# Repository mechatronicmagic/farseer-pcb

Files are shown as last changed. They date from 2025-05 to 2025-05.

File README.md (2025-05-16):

- [Repository Info](#org3efd3b6)
- [Images](#org4000d6c)
- [Schematic](#org9702aa9)
- [PCB](#orgc4c3abc)
- [Bill of Materials](#org9a89b54)
- [Development](#org04cc7a2)

    <!-- This file is generated automatically from metadata -->
    <!-- File edits may be overwritten! -->

# Repository Info

-   Project Name: farseer\_pcb
-   Synopsis: Measures fly wingbeats using IR light reflected from flapping fly wings.
-   Documentation Version: 1.0.0
-   Pcb Version: 1.0
-   Enclosure Version: 1.0
-   Supplemental BOM Version: 1.0
-   Release Date: 2025-05-16
-   Creation Date: 2025-05-16
-   Kicad Version: 9.0.0
-   License: GPL-3.0
-   URL: <https://github.com/mechatronicmagic/farseer_pcb>
-   Author: Peter Polidoro
-   Email: peter@polidoro.io
-   Copyright: 2025 Peter Polidoro
-   References:
    -   [kicad](https://www.kicad.org/)
    -   [light\_sensor\_boards](https://github.com/janelia-kicad/light_sensor_boards)
    -   [wingbeat\_detector](https://github.com/peterpolidoro/wingbeat_detector)
-   Papers:
    -   [Active antennal movements in Drosophila can tune wind encoding](https://doi.org/10.1016/j.cub.2023.01.020)
    -   [A novel assay to evaluate action selection in escape behavior](https://doi.org/10.1016/j.jneumeth.2018.04.019)
    -   [Cellular evidence for efference copy in Drosophila visuomotor processing](https://doi.org/10.1038/nn.4083)
    -   [State-dependent decoupling of sensory and motor circuits underlies behavioral flexibility in Drosophila](https://doi.org/10.1038/s41593-019-0413-4)
    -   [Active flight increases the gain of visual motion processing in Drosophila](https://doi.org/10.1038/nn.2492)
    -   [An Optical Tachometer for Measurement of the Wing-Beat Frequency of Free-Flying Insects](https://doi.org/10.1242/jeb.82.1.377)

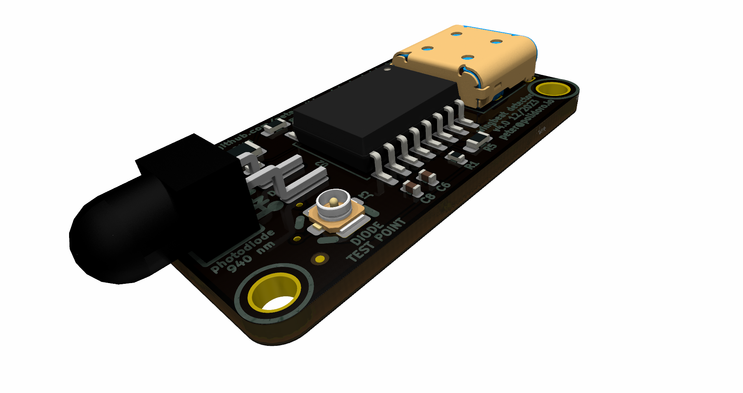
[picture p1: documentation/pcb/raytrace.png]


This wingbeat detector, or flight “tachometer”, is a small electro-optical device that uses reflected infrared light from the fly’s wingbeats to generate an oscillating voltage signal. The oscillation frequency of the voltage signal matches, and thus allows one to measure, the tethered fly's wingbeat frequency.

This device is useful for plate (rather than pin) tethered flight experiments, because with plate-glued flies, one cannot extract the wingbeat frequency via a classical wingbeat analyzer. Microphones have also been used for extracting wingbeat frequency, but they require a quiet room. This wingbeat detector is immune to audible noise and only requires an infrared light source, often already present on flight rigs for video recording.

One end of a small diameter light guide is mounted near the fly and aimed at the wings. The other end of the light guide is in a small enclosure containing an optical filter and printed circuit board and can be mounted off to the side of the rig wherever there is room.

The light guide brings light reflected off of the wings down to a photodiode on a circuit board, after passing through an optical filter to remove the unwanted wavelengths of light. Amplifiers and filters on the circuit board convert the tiny amounts of current from the photodiode into an oscillating voltage signal, with a frequency range of several hundred Hertz and a magnitude range of several Volts.

The oscillating voltage signal can be fed into a data acquisition card, oscilloscope, and/or a speaker for recording and instant feedback on fly wingbeat frequency. Using a threshold, the signal can be used as a simple boolean that indicates whether the tethered animal is flying or not for triggering experiments or synchronizing the data collection.

This device was first created at Caltech in the Dickinson lab in collaboration with Gaby Maimon around 2010. It has transformed over several generations, getting smaller and more robust each iteration. It has been used on rigs in multiple universities and research institutes and has been referenced in several papers. A couple of iterations were designed in collaboration with Sung Soo Kim and the Card lab at Janelia Research Campus. The latest version was created in collaboration with the Suver lab at Vanderbilt.

# Images

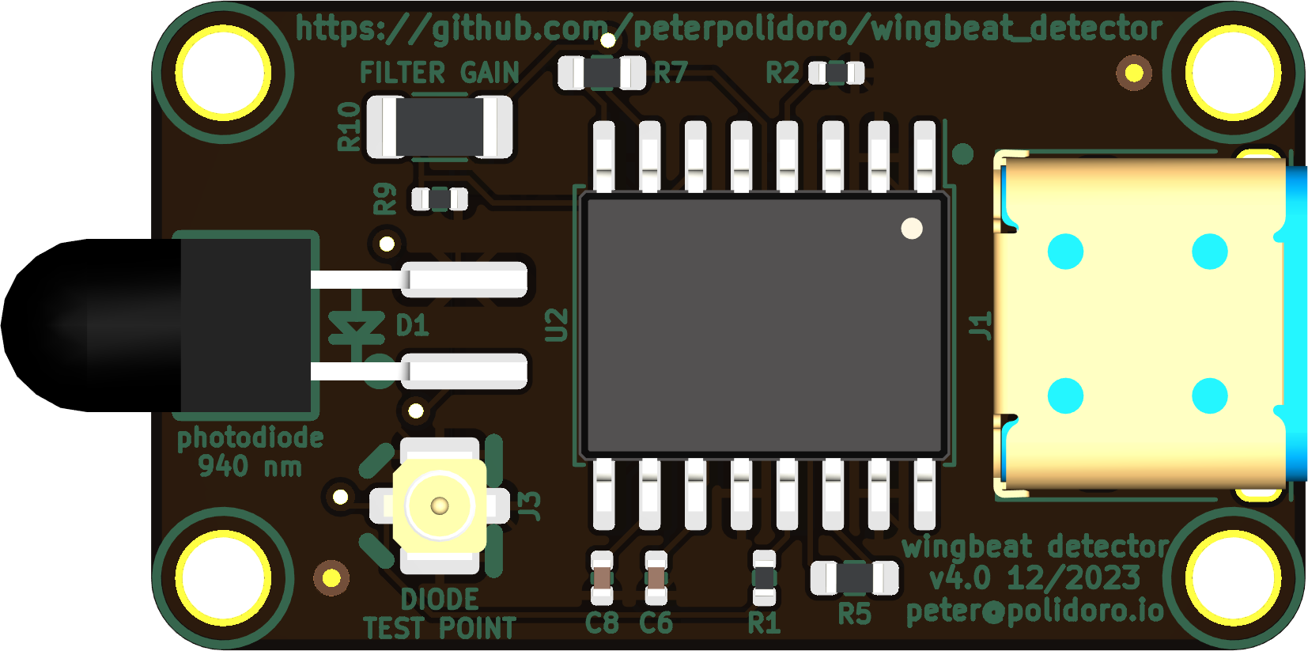
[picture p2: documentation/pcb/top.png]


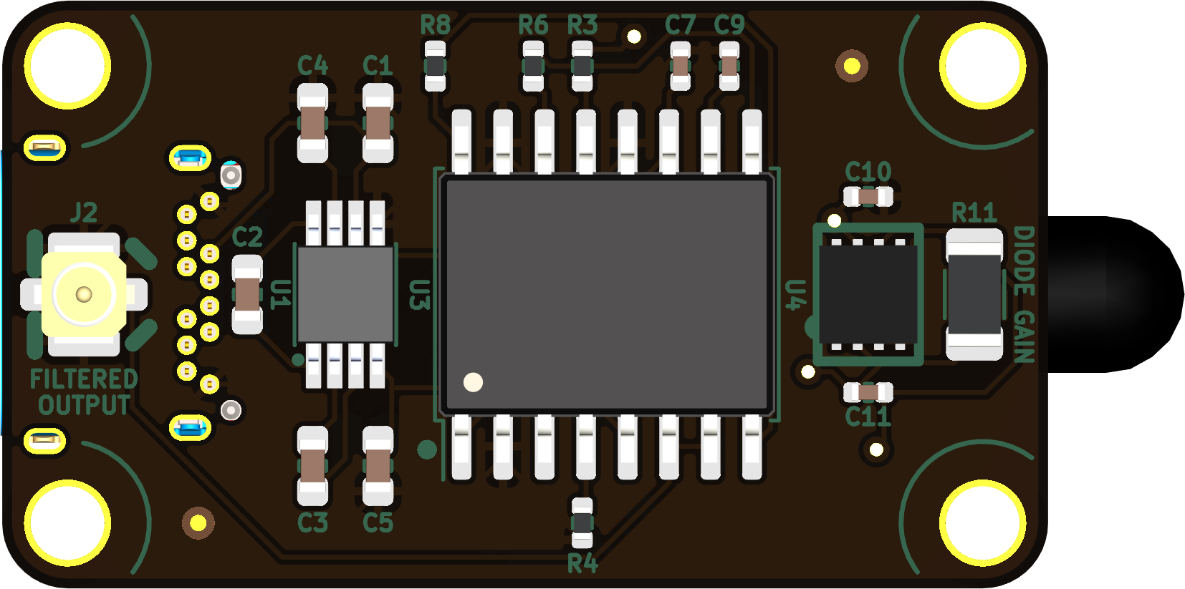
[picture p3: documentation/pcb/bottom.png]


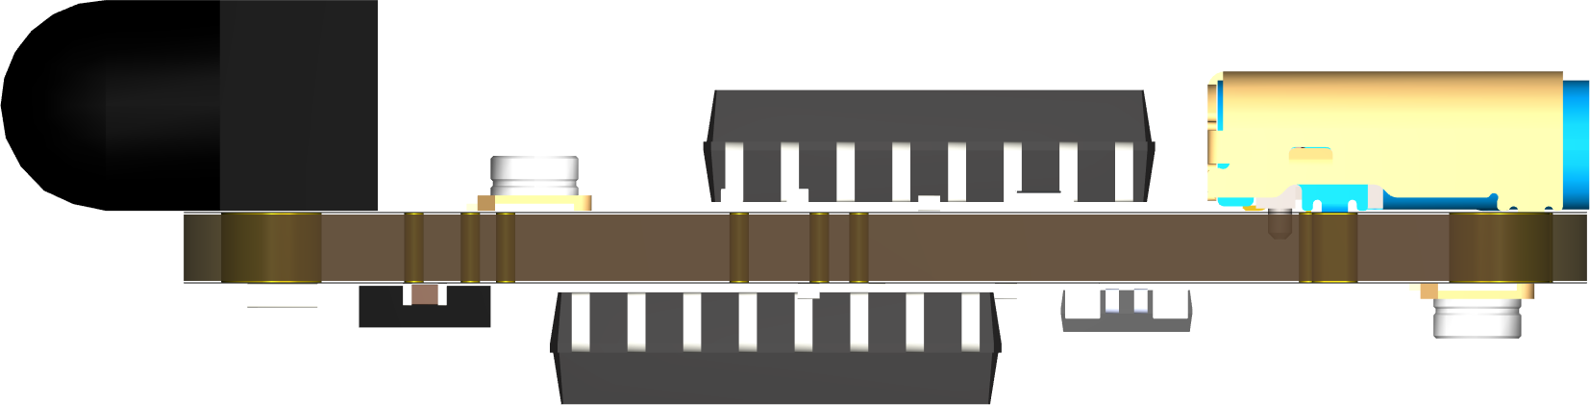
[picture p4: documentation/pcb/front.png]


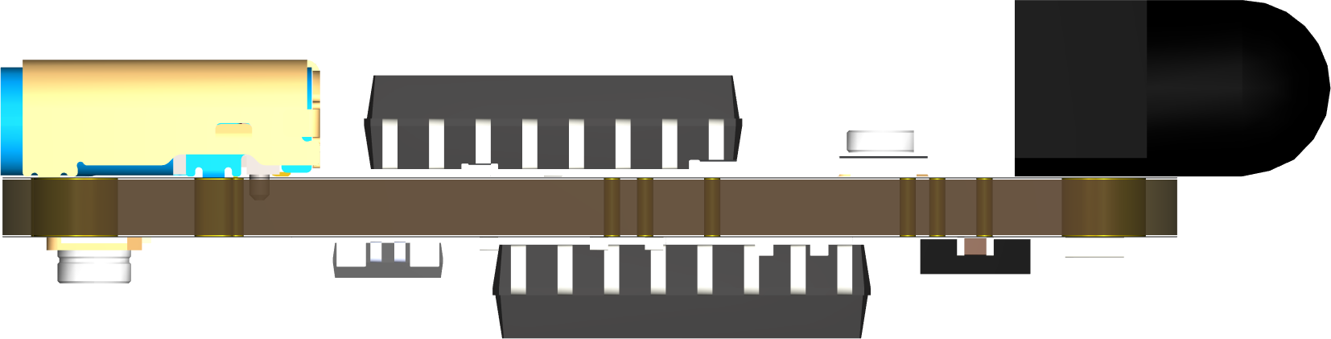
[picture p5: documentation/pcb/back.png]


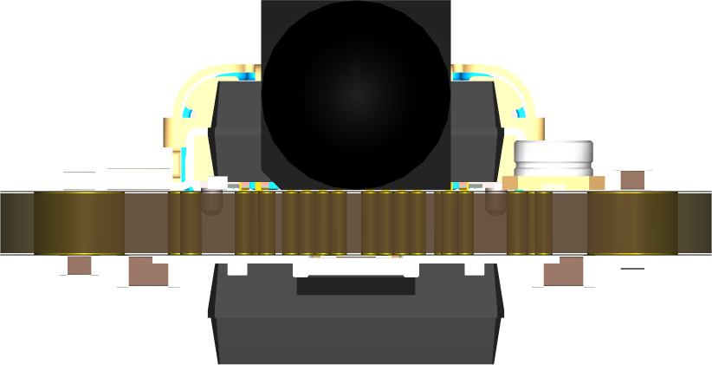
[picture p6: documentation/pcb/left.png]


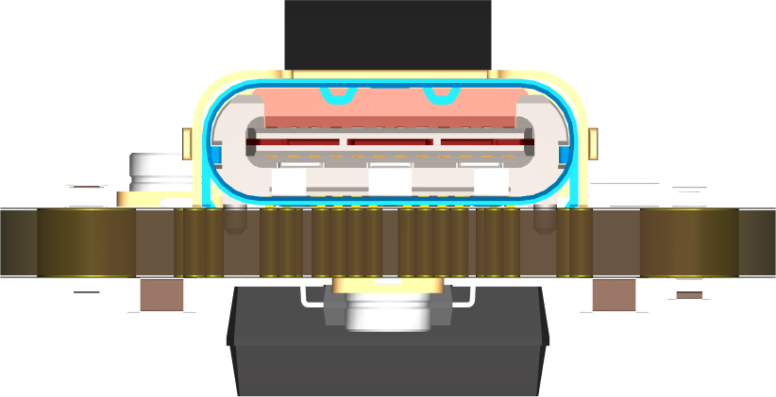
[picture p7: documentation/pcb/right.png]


# Schematic

[./documentation/schematic/wingbeat\_detector.pdf](./documentation/schematic/wingbeat_detector.pdf)











# PCB

# Bill of Materials

## Board

|    |
|--- |
|  |

## Supplemental

| Item | Description | Manufacturer Part Number | Manufacturer | Quantity | Cost | Total |
|---- |--- |--- |--- |--- |--- |--- |
| 1 | BNC STRAIGHT BULKHEAD JACK TO AM | 095-850-210-150 | Amphenol RF | 1 | 24.41  | 24.41 |
| 2 | AC/DC WALL MNT ADAPTER 5.1V 15W | SC0445 | Raspberry Pi | 1 | 8.00 | 8.00 |
| 3 | CBL ASSY BNC PLUG-PLUG RG58 5' | 5697-60 | Pomona Electronics  | 1 | 21.29  | 21.29 |
| 4 | LLG 3 mm Core 420 - 2000 nm 1.2 m  | LLG3-4Z | thorlabs | 1 | 392.69 | 392.69  |
| 5 | 3 mm LLG to SM1 Adapter | AD3LLG | thorlabs | 1 | 38.32  | 38.32 |
| 6 | Adapter External SM05 Internal SM1 | SM1A1 | thorlabs | 1 | 23.41  | 23.41 |
| 7 | SM05 Adjustable Lens Tube | SM05V05 | thorlabs | 1 | 31.64  | 31.64 |
| 8 | 825nm 12.5mm Dia Longpass Filter | 86-062 | edmundoptics | 1 | 194.00 | 194.00  |
| 9 | Universal probe holder | MXB | siskiyou | 1 | 275.00 | 275.00  |
| 10 | MACHINE SCREW PAN PHILLIPS 2-56 | PMSSS 256 0050 PH | B&F Fastener Supply | 4 | 0.24 | 0.96 |
| 11 | HEX NUT 3/16" STN STEEL 2-56 | HNSS256 | B&F Fastener Supply | 4 | 0.28 | 1.12 |
| | Supplemental BOM Version: 1.0 | | | | Total  | 1010.84 |

# Development

## Install Guix

[Install Guix](https://guix.gnu.org/manual/en/html_node/Binary-Installation.html)

## Edit metadata.org

    make metadata-edits

## Tangle metadata.org

    make metadata

## Edit project

    make kicad-edits
    exit

    make filter-edits
    exit

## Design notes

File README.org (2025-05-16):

# This file is generated automatically from metadata
# File edits may be overwritten!
- Project Name: farseer_pcb
- Synopsis: Measures fly wingbeats using IR light reflected from flapping fly wings.
- Documentation Version: 1.0.0
- Pcb Version: 1.0
- Enclosure Version: 1.0
- Supplemental BOM Version: 1.0
- Release Date: 2025-05-16
- Creation Date: 2025-05-16
- Kicad Version: 9.0.0
- License: GPL-3.0
- URL: https://github.com/mechatronicmagic/farseer_pcb
- Author: Peter Polidoro
- Email: peter@polidoro.io
- Copyright: 2025 Peter Polidoro
- References:
  - [[https://www.kicad.org/][kicad]]
  - [[https://github.com/janelia-kicad/light_sensor_boards][light_sensor_boards]]
  - [[https://github.com/peterpolidoro/wingbeat_detector][wingbeat_detector]]
- Papers:
  - [[https://doi.org/10.1016/j.cub.2023.01.020][Active antennal movements in Drosophila can tune wind encoding]]
  - [[https://doi.org/10.1016/j.jneumeth.2018.04.019][A novel assay to evaluate action selection in escape behavior]]
  - [[https://doi.org/10.1038/nn.4083][Cellular evidence for efference copy in Drosophila visuomotor processing]]
  - [[https://doi.org/10.1038/s41593-019-0413-4][State-dependent decoupling of sensory and motor circuits underlies behavioral flexibility in Drosophila]]
  - [[https://doi.org/10.1038/nn.2492][Active flight increases the gain of visual motion processing in Drosophila]]
  - [[https://doi.org/10.1242/jeb.82.1.377][An Optical Tachometer for Measurement of the Wing-Beat Frequency of Free-Flying Insects]]



This wingbeat detector, or flight “tachometer”, is a small electro-optical
device that uses reflected infrared light from the fly’s wingbeats to generate
an oscillating voltage signal. The oscillation frequency of the voltage signal
matches, and thus allows one to measure, the tethered fly's wingbeat frequency.

This device is useful for plate (rather than pin) tethered flight experiments,
because with plate-glued flies, one cannot extract the wingbeat frequency via a
classical wingbeat analyzer. Microphones have also been used for extracting
wingbeat frequency, but they require a quiet room. This wingbeat detector is
immune to audible noise and only requires an infrared light source, often
already present on flight rigs for video recording.

One end of a small diameter light guide is mounted near the fly and aimed at the
wings. The other end of the light guide is in a small enclosure containing an
optical filter and printed circuit board and can be mounted off to the side of
the rig wherever there is room.

The light guide brings light reflected off of the wings down to a photodiode on
a circuit board, after passing through an optical filter to remove the unwanted
wavelengths of light. Amplifiers and filters on the circuit board convert the
tiny amounts of current from the photodiode into an oscillating voltage signal,
with a frequency range of several hundred Hertz and a magnitude range of several
Volts.

The oscillating voltage signal can be fed into a data acquisition card,
oscilloscope, and/or a speaker for recording and instant feedback on fly
wingbeat frequency. Using a threshold, the signal can be used as a simple
boolean that indicates whether the tethered animal is flying or not for
triggering experiments or synchronizing the data collection.

This device was first created at Caltech in the Dickinson lab in collaboration
with Gaby Maimon around 2010. It has transformed over several generations,
getting smaller and more robust each iteration. It has been used on rigs in
multiple universities and research institutes and has been referenced in several
papers. A couple of iterations were designed in collaboration with Sung Soo Kim
and the Card lab at Janelia Research Campus. The latest version was created in
collaboration with the Suver lab at Vanderbilt.

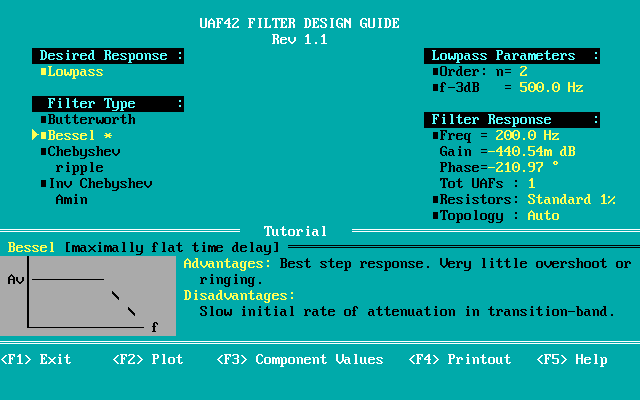
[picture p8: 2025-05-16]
documentation/filter/low-pass-filter-design.png

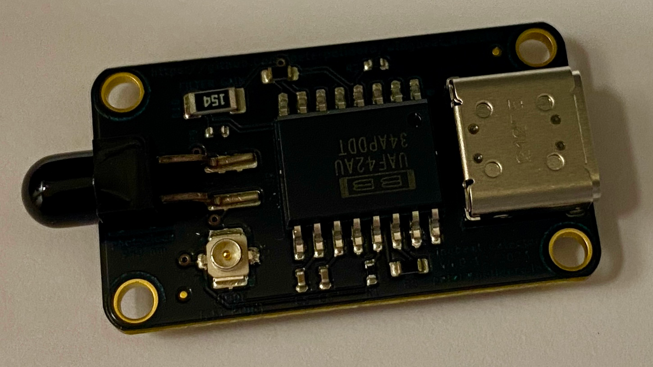
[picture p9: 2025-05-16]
documentation/photos/wingbeat_detector_photo_3.png

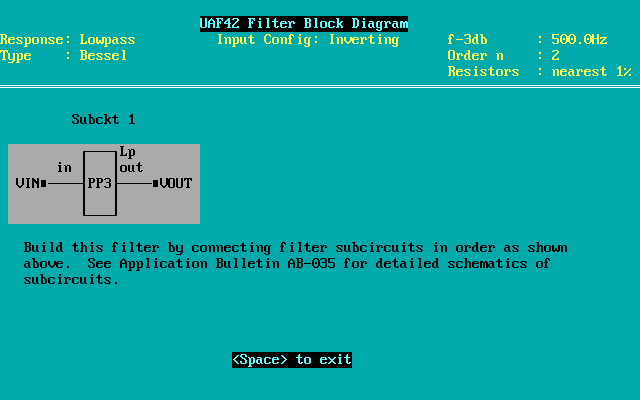
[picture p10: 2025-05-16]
documentation/filter/low-pass-filter-block-diagram.png

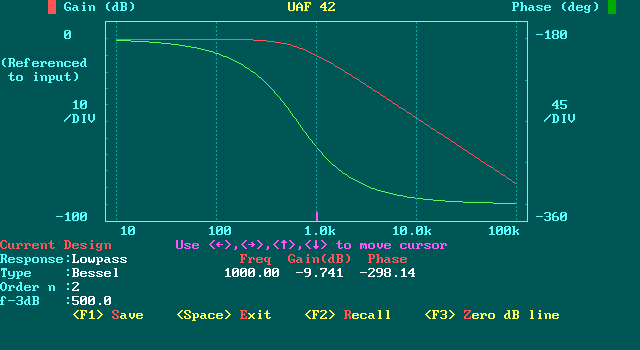
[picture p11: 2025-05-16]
documentation/filter/low-pass-filter-plot.png

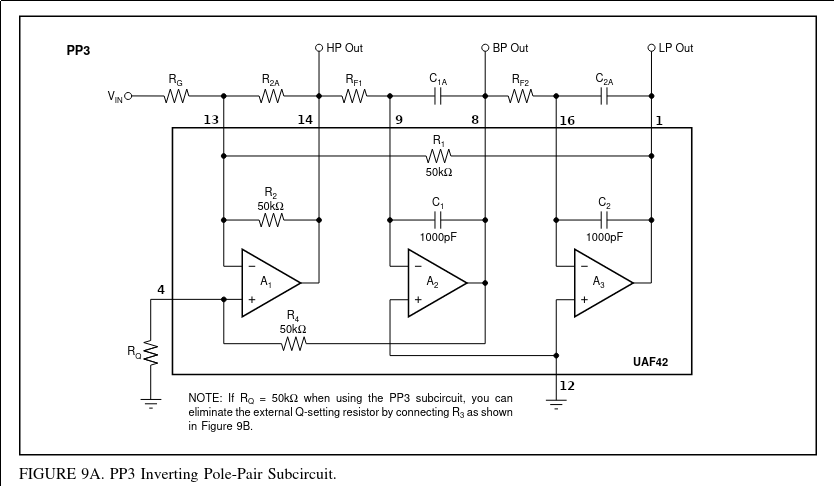
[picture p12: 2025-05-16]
documentation/filter/pp3.png

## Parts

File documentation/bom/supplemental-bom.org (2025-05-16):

#+OPTIONS: toc:nil title:nil num:nil ^:nil
#+LATEX_HEADER: \usepackage{adjustbox}
#+LATEX_HEADER: \usepackage[margin=2cm]{geometry}
* Supplemental BOM
- Project Name: farseer_pcb
- Synopsis: Measures fly wingbeats using IR light reflected from flapping fly wings.
- Release Date: 2025-05-16
- URL: https://github.com/mechatronicmagic/farseer_pcb
- Author: Peter Polidoro
- Email: peter@polidoro.io
#+BEGIN_TABLE
#+LATEX: \adjustbox{max width=\linewidth}{
#+ATTR_LATEX: :center nil
| Item | Description                                            | Manufacturer Part Number | Manufacturer        | Quantity |   Cost |   Total |
|------+--------------------------------------------------------+--------------------------+---------------------+----------+--------+---------|
|    1 | BNC STRAIGHT BULKHEAD JACK TO AM                       | 095-850-210-150          | Amphenol RF         |        1 |  24.41 |   24.41 |
|    2 | AC/DC WALL MNT ADAPTER 5.1V 15W                        | SC0445                   | Raspberry Pi        |        1 |   8.00 |    8.00 |
|    3 | CBL ASSY BNC PLUG-PLUG RG58 5'                         | 5697-60                  | Pomona Electronics  |        1 |  21.29 |   21.29 |
|    4 | LLG 3 mm Core 420 - 2000 nm 1.2 m                      | LLG3-4Z                  | thorlabs            |        1 | 392.69 |  392.69 |
|    5 | 3 mm LLG to SM1 Adapter                                | AD3LLG                   | thorlabs            |        1 |  38.32 |   38.32 |
|    6 | Adapter External SM05 Internal SM1                     | SM1A1                    | thorlabs            |        1 |  23.41 |   23.41 |
|    7 | SM05 Adjustable Lens Tube                              | SM05V05                  | thorlabs            |        1 |  31.64 |   31.64 |
|    8 | 825nm 12.5mm Dia Longpass Filter                       | 86-062                   | edmundoptics        |        1 | 194.00 |  194.00 |
|    9 | Universal probe holder                                 | MXB                      | siskiyou            |        1 | 275.00 |  275.00 |
|   10 | MACHINE SCREW PAN PHILLIPS 2-56                        | PMSSS 256 0050 PH        | B&F Fastener Supply |        4 |   0.24 |    0.96 |
|   11 | HEX NUT 3/16" STN STEEL 2-56                           | HNSS256                  | B&F Fastener Supply |        4 |   0.28 |    1.12 |
|------+--------------------------------------------------------+--------------------------+---------------------+----------+--------+---------|
|      | Supplemental BOM Version: 1.0 |                          |                     |          |  Total | 1010.84 |
#+TBLFM: $7=$5*$6;%0.2f::@>$7=vsum(@2..@-1);%0.2f
#+LATEX: }
#+END_TABLE

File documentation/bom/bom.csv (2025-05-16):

Item | Reference(s) | Quantity | Manufacturer | Manufacturer Part Number | Vendor | Vendor Part Number | Description | Package
1 | C1 C2 C3 C4 C5 | 5 | TDK Corporation | C1608X5R1C475K080AC | Digi-Key | 445-7478-1-ND | CAP CER 4.7UF 16V X5R 0603
2 | C6 C7 C8 C9 | 4 | Yageo | CC0402ZRY5V8BB104 | Digi-Key | 311-1375-1-ND | CAP CER 0.1UF 25V Y5V | 0402
3 | C10 | 1 | Samsung Electro-Mechanics | CL05A105KL5NRNC | Digi-Key | 1276-6796-1-ND | CAP CER 1UF 35V X5R | 0402
4 | C11 | 1 | KEMET | C0402C300J5GACAUTO | Digi-Key | 399-C0402C300J5GACAUTOCT-ND | CAP CER 30PF 50V C0G/NP0 | 0402
5 | D1 | 1 | American Bright Optoelectronics Corporation | BPD-BQDA38V-FZ04 | Digi-Key | BPD-BQDA38V-FZ04CT-ND | SENSOR PHOTODIODE RADIAL
6 | J1 | 1 | Amphenol | 10137062-00021LF | Digi-Key | 609-6109-1-ND | CONN RCP USB3.1 TYPEC 24P SMD RA
7 | J2 J3 | 2 | Amphenol RF | A-1JB | Digi-Key | 115-A-1JBCT-ND | CONN UMC JACK STR 50 OHM SMD
8 | R1 R3 R6 R8 | 4 | Panasonic Electronic Components | ERJ-2RKF4992X | Digi-Key | P49.9KLCT-ND | RES SMD 49.9K OHM 1% 1/10W | 0402
9 | R2 R4 | 2 | Panasonic Electronic Components | ERJ-2RKF6812X | Digi-Key | P68.1KLCT-ND | RES SMD 68.1K OHM 1% 1/10W | 0402
10 | R5 R7 | 2 | Vishay Dale | CRCW06033M65FKEA | Digi-Key | 541-3.65MHCT-ND | RES SMD 3.65M OHM 1% 1/10W | 0603
11 | R9 | 1 | Panasonic Electronic Components | ERJ-2RKF2490X | Digi-Key | P249LCT-ND | RES SMD 249 OHM 1% 1/10W | 0402
12 | R10 | 1 | Panasonic Electronic Components | ERA-8AEB154V | Digi-Key | P150KBCCT-ND | RES SMD 150K OHM 0.1% 1/4W | 1206
13 | R11 | 1 | Panasonic Electronic Components | ERJ-PM8F2004V | Digi-Key | 10-ERJ-PM8F2004VCT-ND | RES 2.0M OHM 1% 0.66W | 1206
14 | U1 | 1 | Maxim Integrated | MAX865EUA+ | Digi-Key | MAX865EUA+-ND | IC REG CHARGE PUMP INV DL 8UMAX | SOP65P490X110-8N
15 | U2 U3 | 2 | Texas Instruments | UAF42AU | Digi-Key | UAF42AU-ND | IC UNIV ACTIVE FILTER 16-SOIC
16 | U4 | 1 | Texas Instruments | OPA381AIDRBT | Digi-Key | 296-17363-1-ND | IC TRANSIMPEDANCE 1 CIRCUIT 8SON

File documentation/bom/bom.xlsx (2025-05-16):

Item | Reference(s) | Quantity | Manufacturer | Manufacturer Part Number | Vendor | Vendor Part Number | Description | Package
1 | C1 C2 C3 C4 C5 C13 | 6 | TDK Corporation | C1608X5R1C475K080AC | Digi-Key | 445-7478-1-ND | CAP CER 4.7UF 16V X5R 0603
2 | C6 C7 C8 C9 C10 C12 | 6 | Yageo | CC0402ZRY5V8BB104 | Digi-Key | 311-1375-1-ND | CAP CER 0.1UF 25V Y5V | 402
3 | C11 | 1 | TDK Corporation | CGA2B2C0G1H020C050BA | Digi-Key | 445-5572-1-ND | CAP CER 2PF 50V C0G | 402
4 | D1 | 1 | American Bright Optoelectronics Corporation | BPD-BQDA38V-FZ04 | Digi-Key | BPD-BQDA38V-FZ04CT-ND | SENSOR PHOTODIODE RADIAL
5 | D2 | 1 | American Bright Optoelectronics Corporation | BIR-BM17J8V-FZ04 | Digi-Key | BIR-BM17J8V-FZ04CT-ND | 5MM 940 IR
6 | J1 | 1 | Amphenol | 10137062-00021LF | Digi-Key | 609-6109-1-ND | CONN RCP USB3.1 TYPEC 24P SMD RA
7 | J2 J3 J4 | 3 | Amphenol RF | A-1JB | Digi-Key | 115-A-1JBCT-ND | CONN UMC JACK STR 50 OHM SMD
8 | Q1 | 1 | Texas Instruments | CSD17483F4 | Digi-Key | 296-38914-1-ND | MOSFET N-CH 30V 1.5A 3PICOSTAR
9 | R1 R3 R6 R8 R10 R11 R12 R14 R16 | 9 | Panasonic Electronic Components | ERJ-2RKF4992X | Digi-Key | P49.9KLCT-ND | RES SMD 49.9K OHM 1% 1/10W | 402
10 | R2 R4 | 2 | Panasonic Electronic Components | ERJ-2RKF6812X | Digi-Key | P68.1KLCT-ND | RES SMD 68.1K OHM 1% 1/10W | 402
11 | R5 R7 | 2 | Vishay Dale | CRCW06033M65FKEA | Digi-Key | 541-3.65MHCT-ND | RES SMD 3.65M OHM 1% 1/10W | 603
12 | R9 | 1 | Panasonic Electronic Components | ERJ-2RKF2490X | Digi-Key | P249LCT-ND | RES SMD 249 OHM 1% 1/10W | 402
13 | R13 R15 | 2 | Panasonic Electronic Components | ERJ-2RKF2322X | Digi-Key | P23.2KLCT-ND | RES SMD 23.2K OHM 1% 1/10W | 402
14 | R17 | 1 | Panasonic Electronic Components | ERJ-2RKF2001X | Digi-Key | P2.00KLCT-ND | RES SMD 2K OHM 1% 1/10W | 402
15 | RV1 RV2 | 2 | Bourns Inc. | 3223W-1-504E | Digi-Key | 3223W-1-504ECT-ND | TRIMMER 500K OHM 0.125W J LEAD
16 | U1 | 1 | Maxim Integrated | MAX865EUA+ | Digi-Key | MAX865EUA+-ND | IC REG CHARGE PUMP INV DL 8UMAX | SOP65P490X110-8N
17 | U2 U3 | 2 | Texas Instruments | UAF42AU | Digi-Key | UAF42AU-ND | IC UNIV ACTIVE FILTER 16-SOIC
18 | U4 | 1 | Texas Instruments | OPA381AIDRBT | Digi-Key | 296-17363-1-ND | IC TRANSIMPEDANCE 1 CIRCUIT 8SON
19 | U5 | 1 | STMicroelectronics | TSV630IQ1T | Digi-Key | 497-17045-1-ND | IC OPAMP GP 1 CIRCUIT | 6DFN
20 | U6 | 1 | American Bright Optoelectronics Corporation | AB-EZPC-10 | Digi-Key | AB-EZPC-10CT-ND | IC LED DRIVER LINEAR 50MA | 6DFN

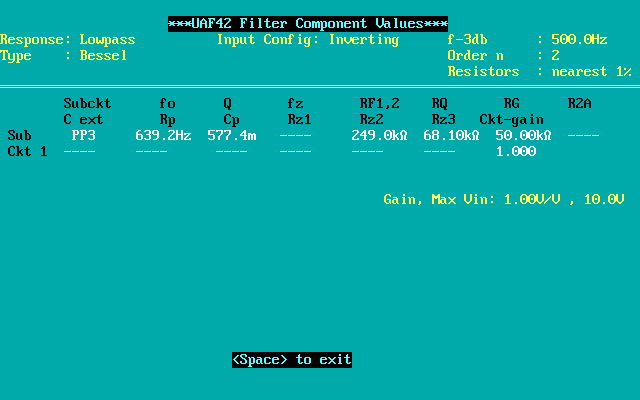
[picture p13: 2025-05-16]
documentation/filter/low-pass-filter-components.png

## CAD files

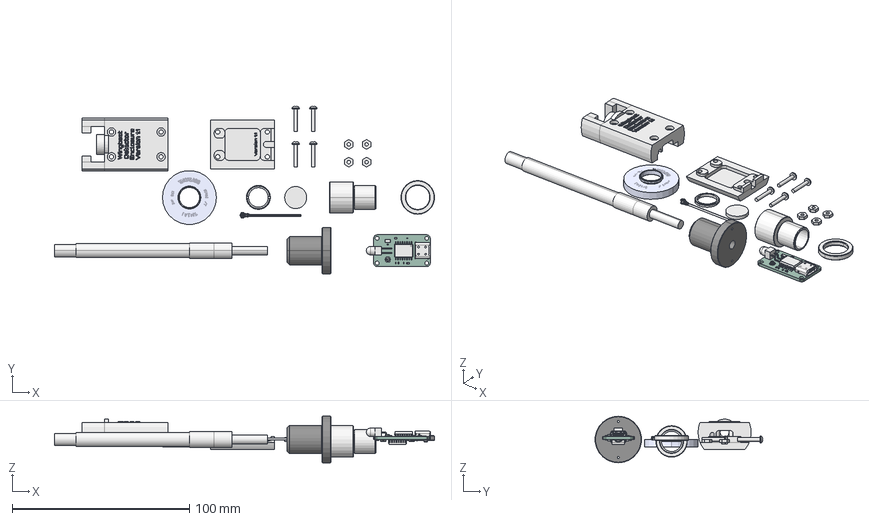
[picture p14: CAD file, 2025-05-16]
documentation/3dmodels/freecad/documentation.FCStd
214.6 x 94.6 x 26.3 mm
wingbeat_detector PCB
enclosure-top001
enclosure-bottom001
screw001
screw002
screw003
screw004
nut001
nut002
nut003
nut004
tube001
tube-nut001
lens-nut
ֱ2_86062
1691-E0W

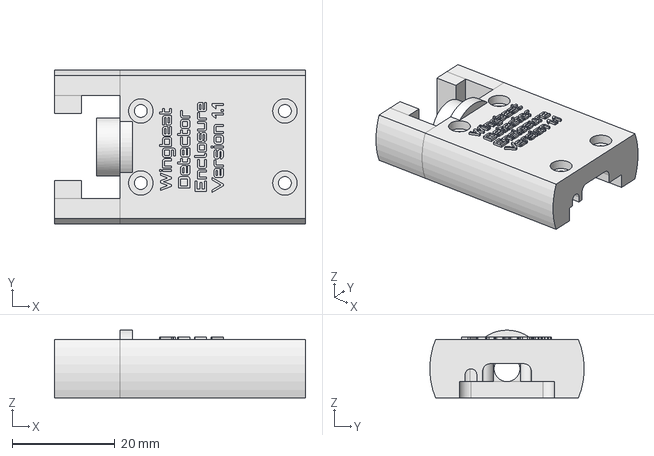
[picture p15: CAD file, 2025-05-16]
documentation/3dmodels/step/wingbeat-detector-enclosure-top.step
48.8 x 30.0 x 13.2 mm

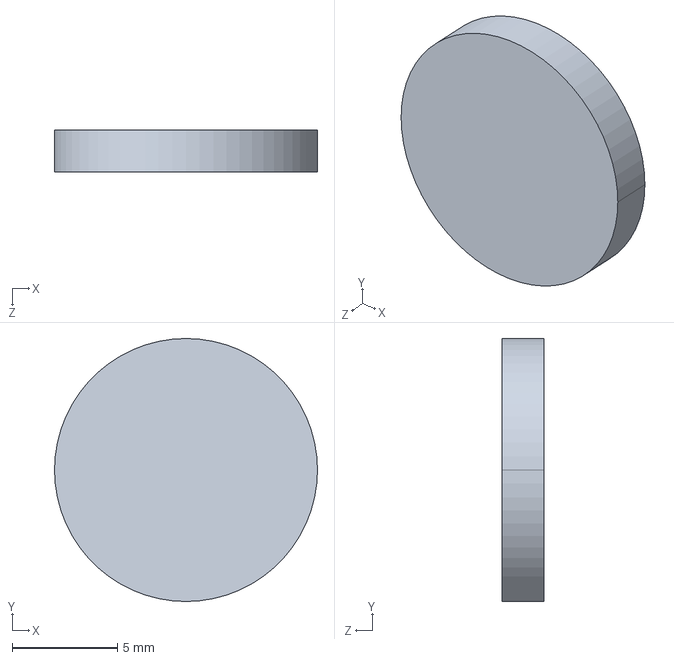
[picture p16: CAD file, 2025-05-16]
documentation/3dmodels/step/filter.step
12.5 x 12.5 x 2.00 mm

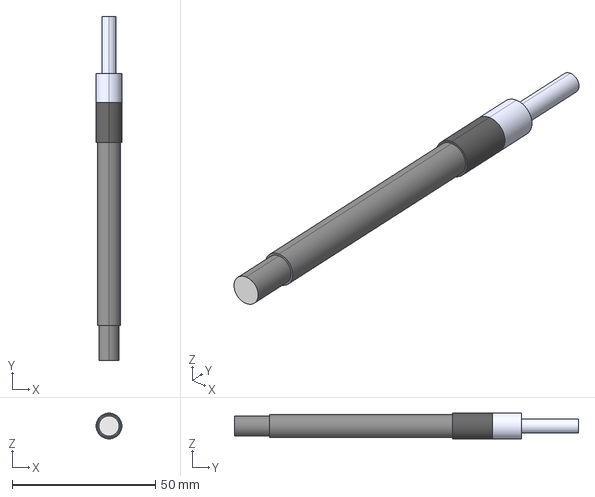
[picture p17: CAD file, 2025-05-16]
documentation/3dmodels/step/LLG-trimmed.step
9.00 x 120.2 x 9.00 mm

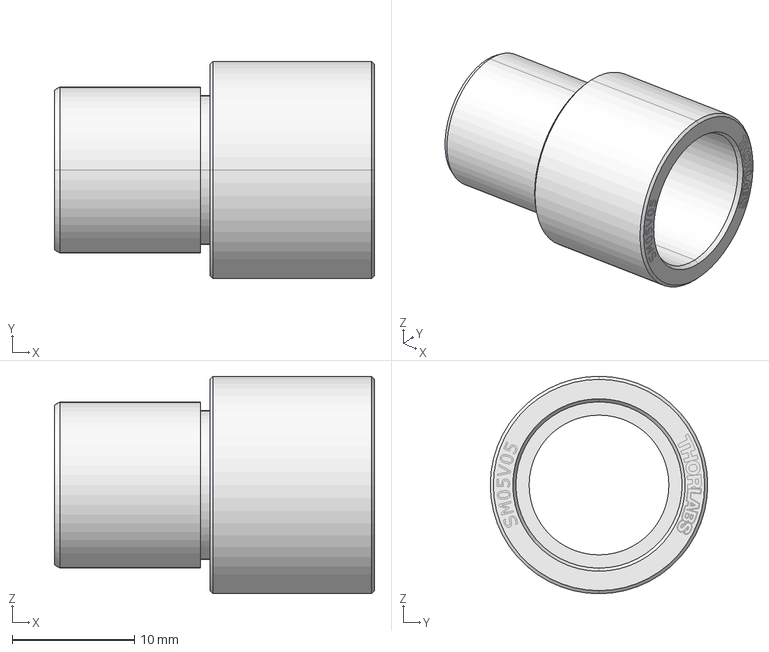
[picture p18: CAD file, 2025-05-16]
documentation/3dmodels/step/tube.step
26.2 x 17.8 x 17.8 mm

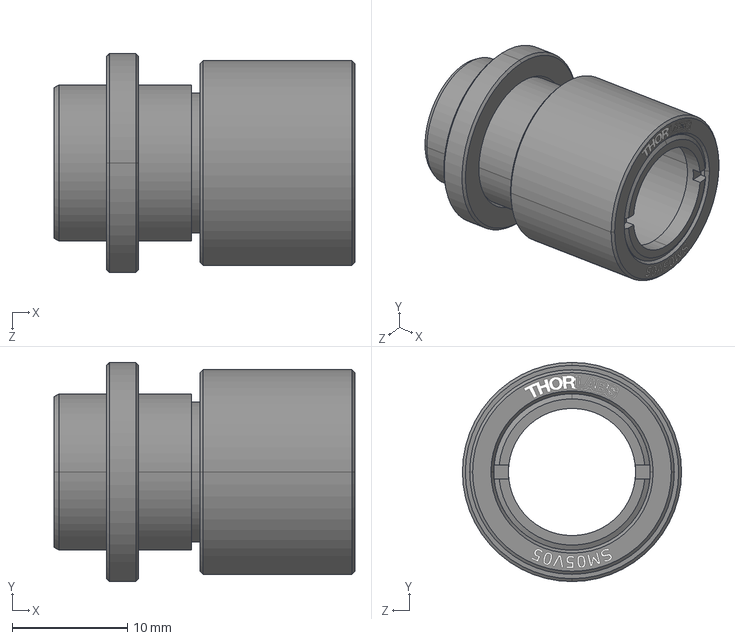
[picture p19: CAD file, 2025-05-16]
documentation/3dmodels/step/SM05V05.step
26.2 x 19.1 x 19.1 mm

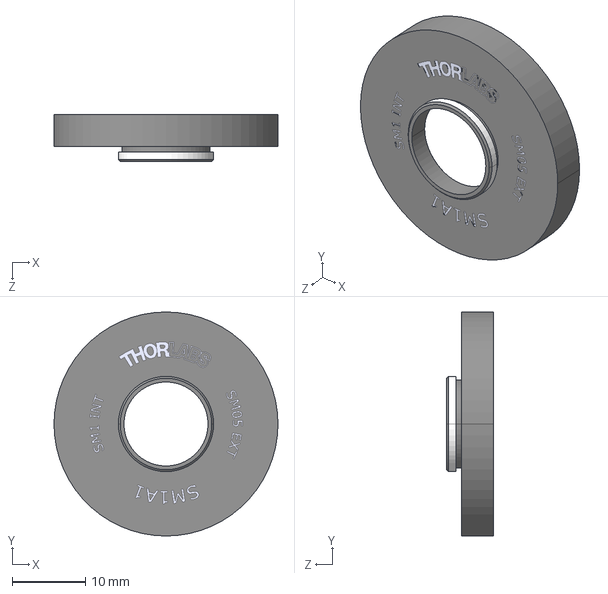
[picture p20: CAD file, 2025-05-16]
documentation/3dmodels/step/SM1A1.step
30.5 x 30.5 x 6.35 mm

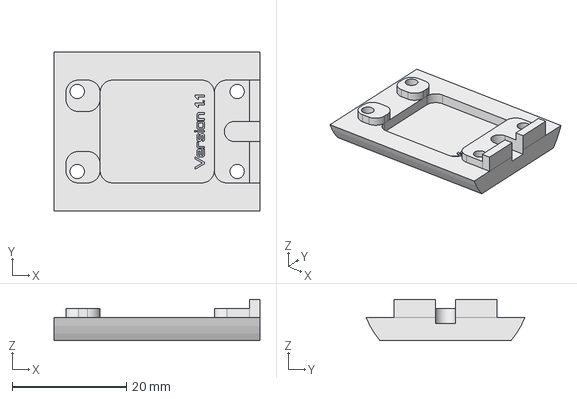
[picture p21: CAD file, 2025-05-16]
documentation/3dmodels/step/wingbeat-detector-enclosure-bottom.step
36.1 x 27.8 x 7.21 mm

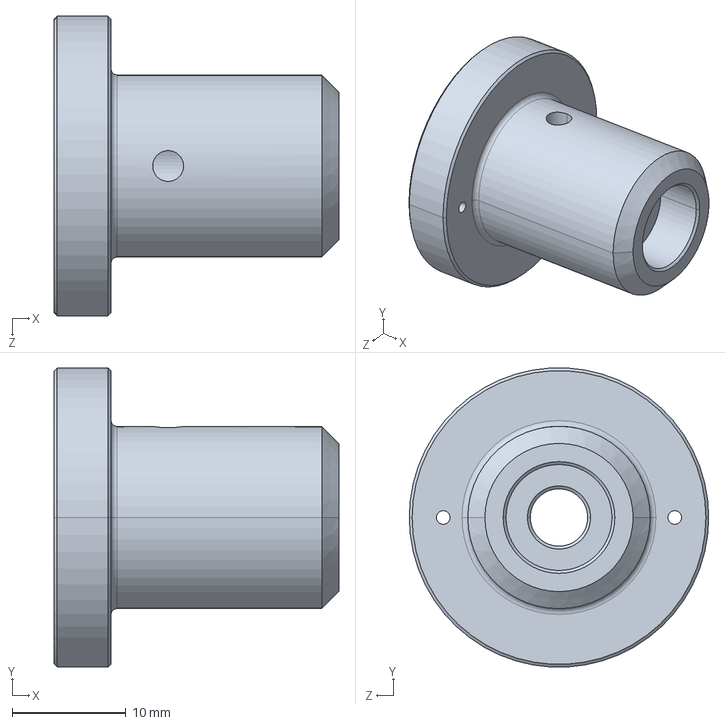
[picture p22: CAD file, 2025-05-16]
documentation/3dmodels/step/AD3LLG.step
25.0 x 26.2 x 26.3 mm

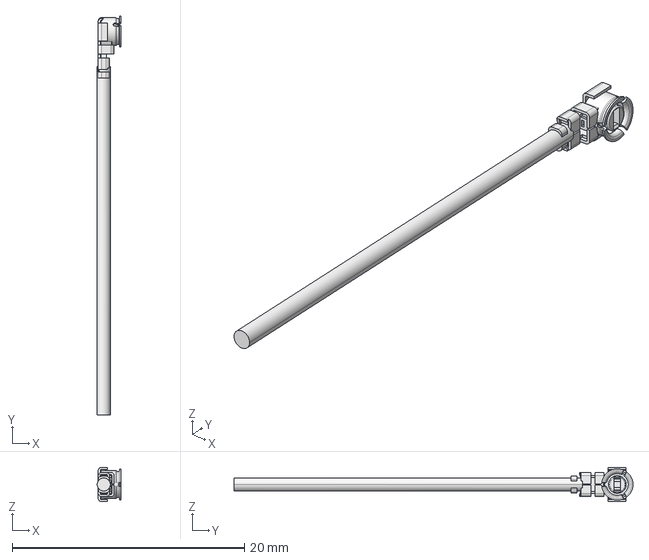
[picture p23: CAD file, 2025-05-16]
documentation/3dmodels/step/AMC-plug.step
2.03 x 34.4 x 2.95 mm

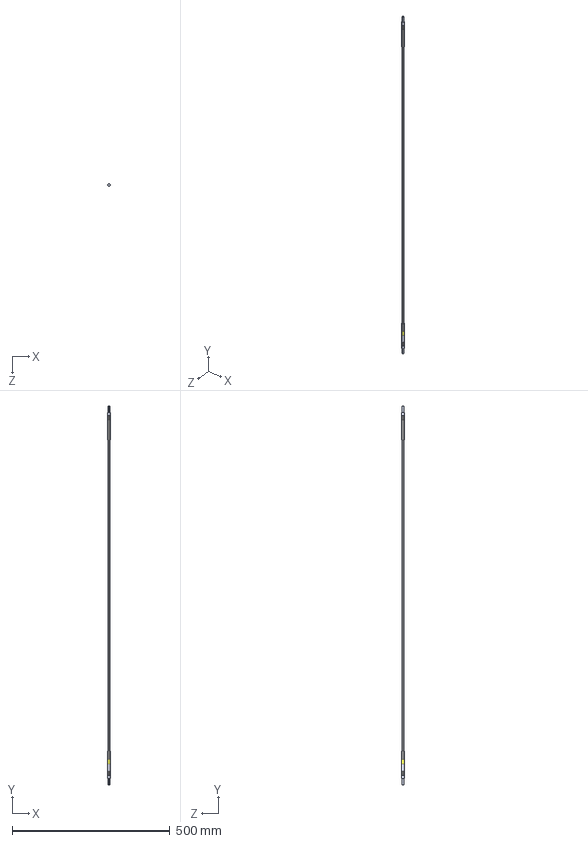
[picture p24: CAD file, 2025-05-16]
documentation/3dmodels/step/LLG3-4Z.step
9.00 x 1200.0 x 9.00 mm

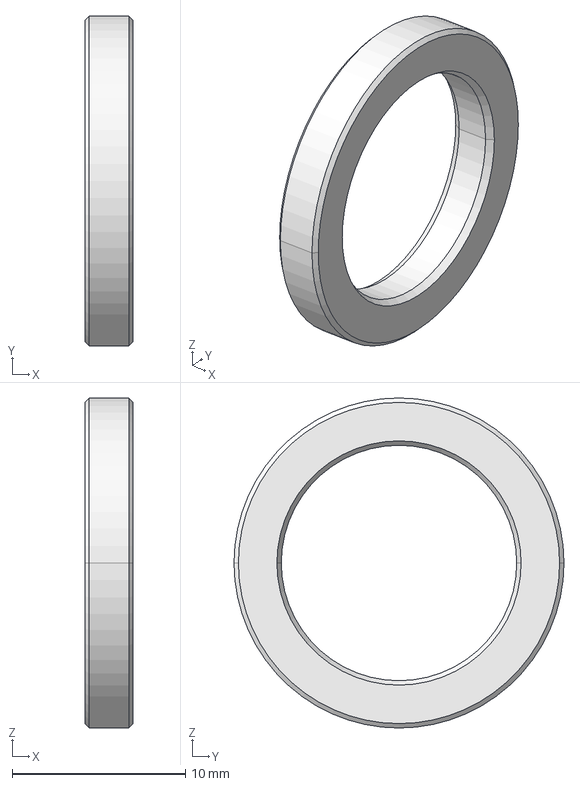
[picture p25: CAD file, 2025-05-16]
documentation/3dmodels/step/tube-nut.step
2.79 x 19.1 x 19.1 mm

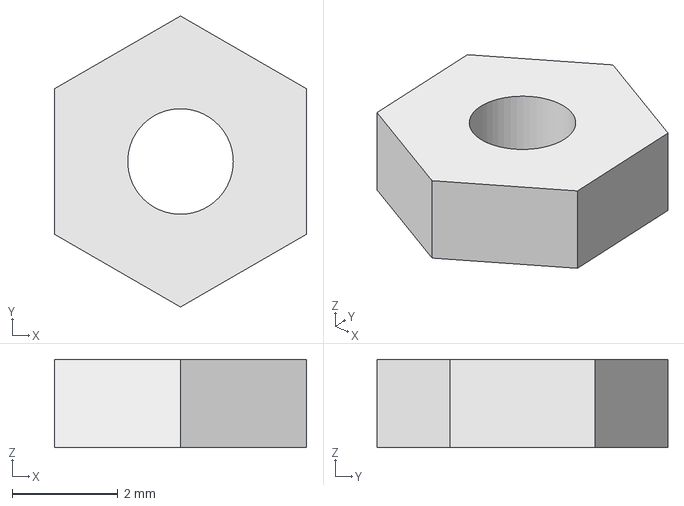
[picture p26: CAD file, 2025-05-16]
documentation/3dmodels/step/nut.step
4.78 x 5.51 x 1.68 mm

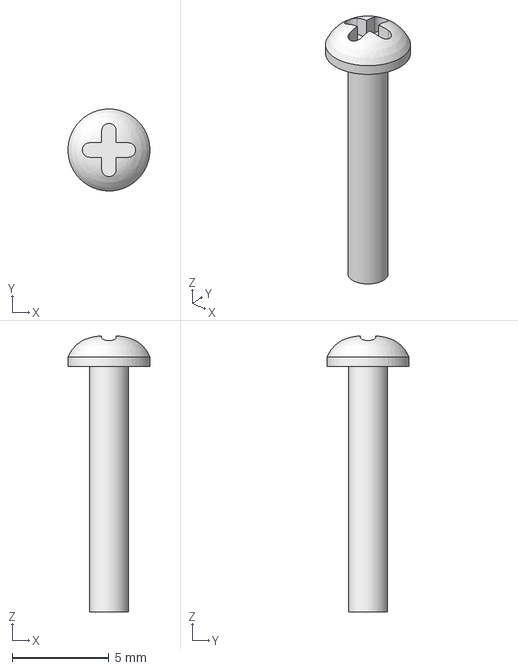
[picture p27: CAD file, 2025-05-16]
documentation/3dmodels/step/screw.step
4.24 x 4.24 x 14.3 mm

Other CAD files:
documentation/3dmodels/step/tube-lens-nut.step

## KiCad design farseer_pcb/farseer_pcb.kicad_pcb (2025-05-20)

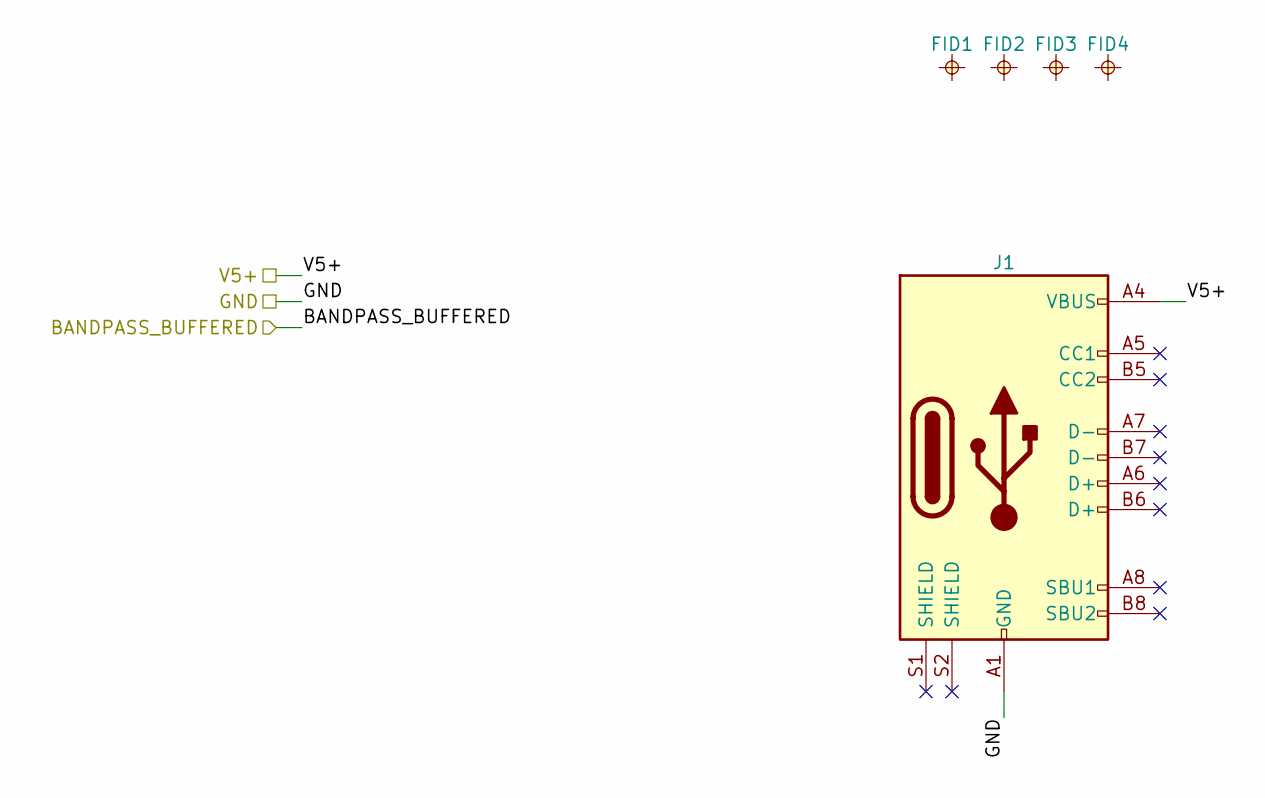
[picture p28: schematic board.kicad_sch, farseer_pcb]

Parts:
FID1, FID2, FID3, FID4: FIDUCIAL_0.5mm_MASK1mm; FIDUCIAL_0.5mm_Mask1mm
J1: Connector_USB_C_Receptacle_USB2.0_16P_GT-USB-7047C; USB_C_Receptacle_GT-USB-7047C_16P_TopMnt_Horizontal; Manufacturer Part Number GT-USB-7047C; LCSC C963218

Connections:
/GND: J1.A1 (GND), J1.A12 (GND), J1.B1 (GND), J1.B12 (GND); also elsewhere on the board
/V5+: J1.A4 (VBUS), J1.A9 (VBUS), J1.B4 (VBUS), J1.B9 (VBUS); also elsewhere on the board

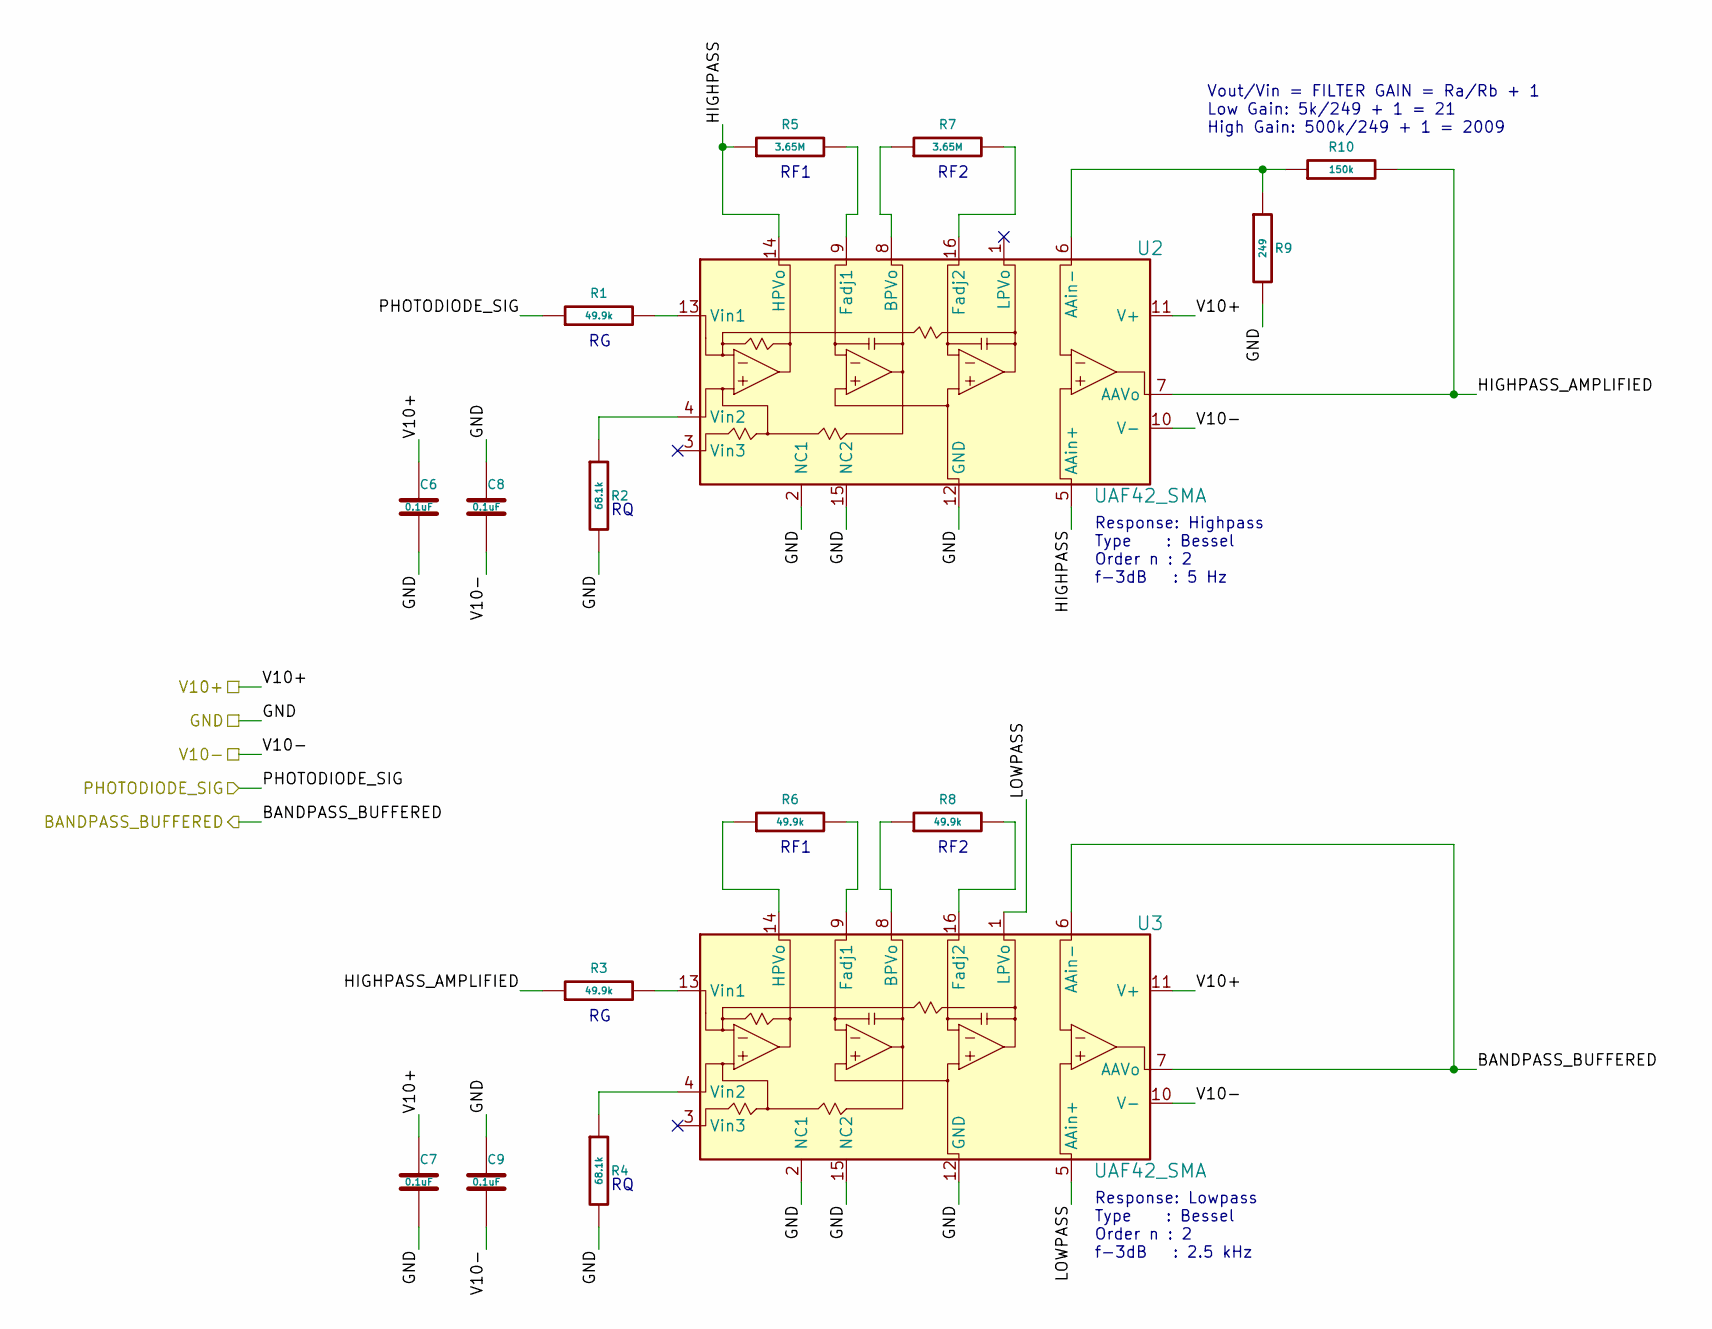
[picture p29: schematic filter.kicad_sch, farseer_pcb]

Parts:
C6, C7, C8, C9: 0.1uF; C_0402_1005Metric; Manufacturer Part Number CC0402ZRY5V8BB104
R1, R3, R6, R8: 49.9k; R_0402_1005Metric; Manufacturer Part Number ERJ-2RKF4992X
R2, R4: 68.1k; R_0402_1005Metric; Manufacturer Part Number ERJ-2RKF6812X
R5, R7: 3.65M; R_0603_1608Metric; Manufacturer Part Number CRCW06033M65FKEA
R9: 249; R_0402_1005Metric; Manufacturer Part Number ERJ-2RKF2490X
R10: 150k; R_1206_3216Metric; Manufacturer Part Number ERA-8AEB154V
U2, U3: UAF42_SMA; SOIC-16W_7.5x10.3mm_P1.27mm; Manufacturer Part Number UAF42AU

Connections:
/BANDPASS_BUFFERED: U3.6 (AAin-), U3.7 (AAVo)
/GND: C6.2, C7.2, C8.1, C9.1, R2.2, R4.2, R9.2, U2.2 (NC1), U2.12 (GND), U2.15 (NC2), U3.2 (NC1), U3.12 (GND), U3.15 (NC2); also elsewhere on the board
/PHOTODIODE_SIG: R1.1; also elsewhere on the board
/V10+: C6.1, C7.1, U2.11 (V+), U3.11 (V+); also elsewhere on the board
/V10-: C8.2, C9.2, U2.10 (V-), U3.10 (V-); also elsewhere on the board
/filter/HIGHPASS: R5.1, U2.5 (AAin+), U2.14 (HPVo)
/filter/HIGHPASS_AMPLIFIED: R3.1, R10.2, U2.7 (AAVo)
/filter/LOWPASS: U3.1 (LPVo), U3.5 (AAin+)
unnamed: R9.1, R10.1, U2.6 (AAin-)
unnamed: R7.1, U2.8 (BPVo)
unnamed: R5.2, U2.9 (Fadj1)
unnamed: R7.2, U2.16 (Fadj2)
unnamed: R1.2, U2.13 (Vin1)
unnamed: R2.1, U2.4 (Vin2)
unnamed: R8.1, U3.8 (BPVo)
unnamed: R6.2, U3.9 (Fadj1)
unnamed: R8.2, U3.16 (Fadj2)
unnamed: R6.1, U3.14 (HPVo)
unnamed: R3.2, U3.13 (Vin1)
unnamed: R4.1, U3.4 (Vin2)

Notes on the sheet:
RF2
Response: Lowpass Type : Bessel Order n : 2 f-3dB : 2.5 kHz
RF1
Vout/Vin = FILTER GAIN = Ra/Rb + 1 Low Gain: 5k/249 + 1 = 21 High Gain: 500k/249 + 1 = 2009
Response: Highpass Type : Bessel Order n : 2 f-3dB : 5 Hz

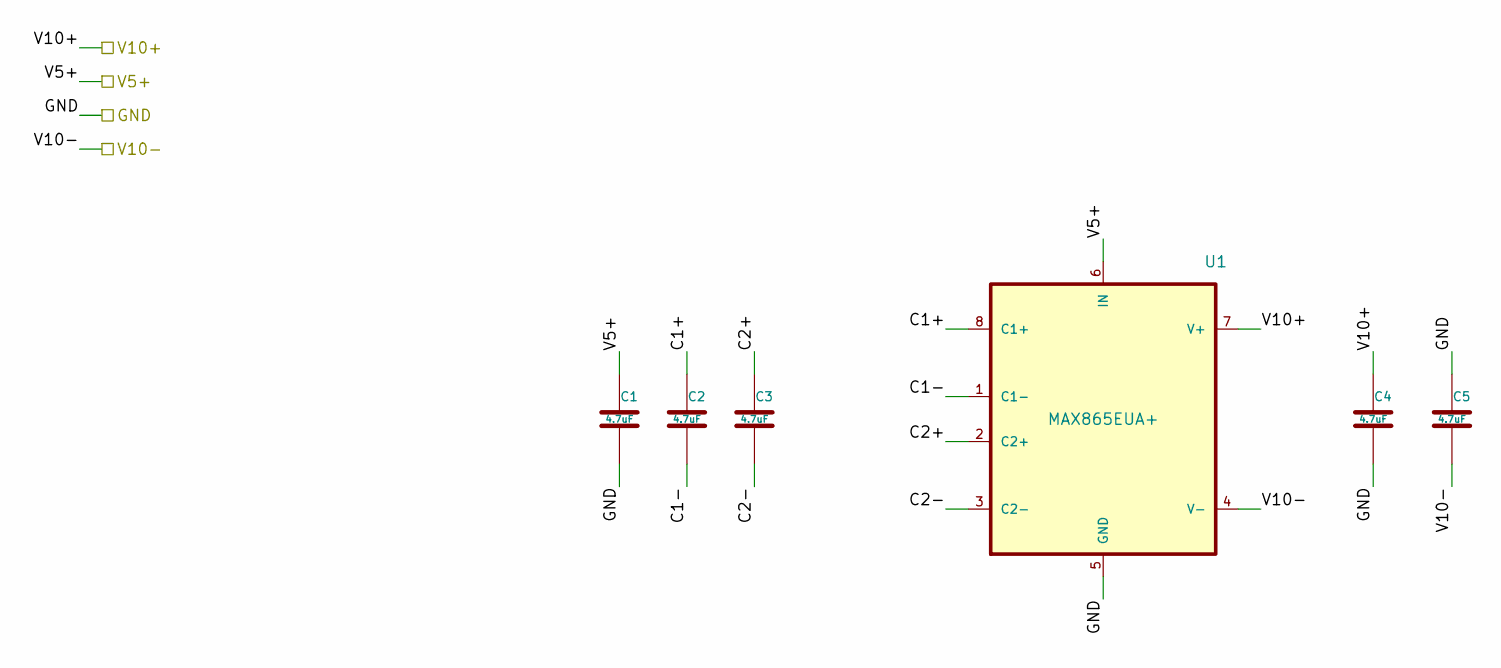
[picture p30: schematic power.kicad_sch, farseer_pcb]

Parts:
C1, C2, C3, C4, C5: 4.7uF; C_0603_1608Metric; Manufacturer Part Number C1608X5R1C475K080AC
U1: MAX865EUA+; SOP65P490X110-8N; Manufacturer Part Number MAX865EUA+

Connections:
/GND: C1.2, C4.2, C5.1, U1.5 (GND); also elsewhere on the board
/V5+: C1.1, U1.6 (IN); also elsewhere on the board
/V10+: C4.1, U1.7 (V+); also elsewhere on the board
/V10-: C5.2, U1.4 (V-); also elsewhere on the board
/power/C1+: C2.1, U1.8 (C1+)
/power/C1-: C2.2, U1.1 (C1-)
/power/C2+: C3.1, U1.2 (C2+)
/power/C2-: C3.2, U1.3 (C2-)

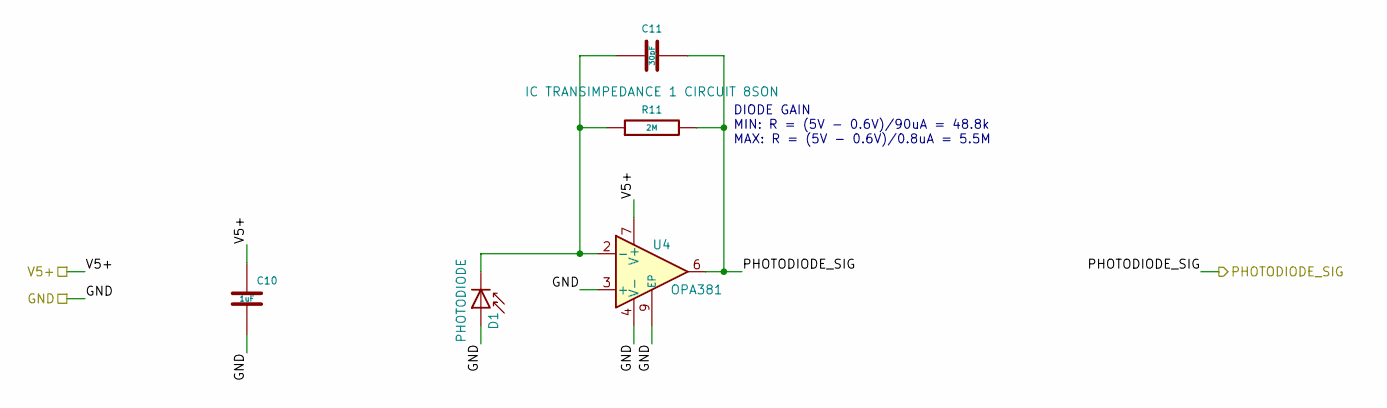
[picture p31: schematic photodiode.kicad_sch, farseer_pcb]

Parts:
C10: 1uF; C_0402_1005Metric; Manufacturer Part Number CL05A105KL5NRNC; LCSC C307413
C11: 30pF; C_0402_1005Metric; Manufacturer Part Number C0402C300J5GACAUTO
D1: PHOTODIODE; PHOTODIODE_RADIAL_RA_SMD_BRIGHT; Manufacturer Part Number BPD-BQDA38V-FZ04
R11: 2M; R_1206_3216Metric; Manufacturer Part Number ERJ-PM8F2004V
U4: OPA381; VSON-8-1EP_3x3mm_P0.65mm_EP1.65x2.4mm; Manufacturer Part Number OPA381AIDRBT

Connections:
/GND: C10.2, D1.2 (A), U4.3 (+), U4.4 (V-), U4.9 (EP); also elsewhere on the board
/PHOTODIODE_SIG: C11.2, R11.2, U4.6; also elsewhere on the board
/V5+: C10.1, U4.7 (V+); also elsewhere on the board
unnamed: C11.1, D1.1 (K), R11.1, U4.2 (-)

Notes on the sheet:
DIODE GAIN MIN: R = (5V - 0.6V)/90uA = 48.8k MAX: R = (5V - 0.6V)/0.8uA = 5.5M

Board: 4 copper layers, 32 parts (19 on the bottom side), 26 nets, no tracks yet.

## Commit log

2025-05-16 Do not remove components from simulation
    [assembly.kicad_sch, filter.kicad_sch, photodiode.kicad_sch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]
2025-05-16 Update filter design
2025-05-20 Begin board resize
    [assembly.kicad_sch, board.kicad_sch, farseer_pcb.kicad_pcb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]
2025-05-20 Add filter to supplemental bom
